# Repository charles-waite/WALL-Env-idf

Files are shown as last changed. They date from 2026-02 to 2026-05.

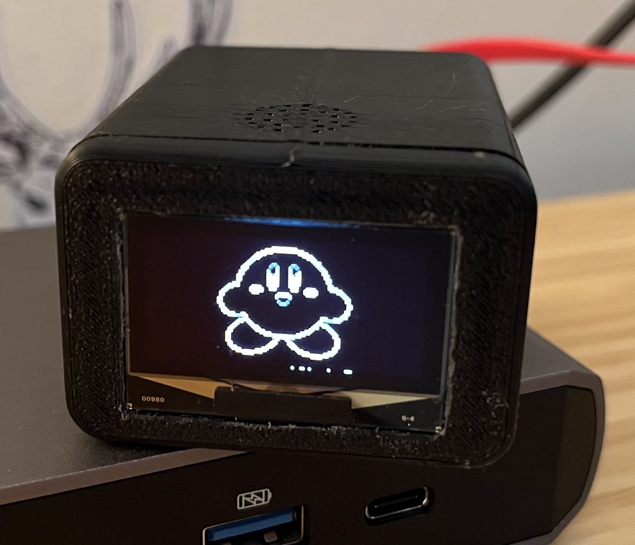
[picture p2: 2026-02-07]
reference/Kirbyartifacts.jpeg

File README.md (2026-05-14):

# WALL-Env ESP-IDF Environmental Sensor

### A compact, Matter-over-Thread environmental monitoring module built around ESP32-C6 boards and a Bosch BME680 sensor. 
It is compatible with both **Apple Home** and **Home Assistant** but requires a Thread-capable Matter controller in order to work. Apple TV 4K (2nd/3rd Gen Wi-Fi+Ethernet), HomePod (2nd Gen), and HomePod mini are all compatible.

This repository is a rewrite of the earlier [Arduino/ESP-IDF WALL-Env firmware](https://github.com/charles-waite/ESP32-Matter-Environmental-Sensor) using native ESP-IDF + esp-matter. The goal is a cleaner codebase with better Matter integration, support for Matter over Thread, board-specific build outputs, and OTA firmware update support.

## 📦 Overview

WALL-Env measures indoor environmental conditions using a Bosch BME680 with Bosch's BSEC2 library calculating accurate sensor data. The device publishes temperature, relative humidity, air quality, CO2 equivalent, and TVOC through Matter over Thread.

Optional support for a 1.3" SH1106 OLED connected via I2C shows commissioning and local status. When the device is uncommissioned, the OLED displays the Matter QR code for simple pairing to Apple Home or Home Assistant.

The firmware is Thread-only. BLE is used for Matter commissioning using an iPhone or iPad using Apple Home or the Home Assistant app. Sensor data and communication runs over Thread.

## 🧰 Hardware

| Component | Description / Notes |
|---|---|
| **Seeed Studio XIAO ESP32-C6** | Primary board target. Uses 4 MB flash and default XIAO-style I2C pins. |
| *OR* | | 
| **Generic ESP32-C6 Supermini** | Secondary board profile with separate I2C pins and Product ID. |
| **Bosch BME680** | Environmental sensor used with BSEC2 for compensated temperature, humidity, s-IAQ, eCO2, and bVOC/TVOC. Connected over I2C at `0x77`. |
| **Optional: 1.3" OLED display"** | Local display connected over I2C at `0x3C`. Current driver assumes a 128x64 panel with a 2-pixel SH1106 column offset. |
| **Standard Apple 5w USB charger** | Designed for always-on USB power. The firmware configures the node as Thread router-capable. |

###Default XIAO wiring

| XIAO ESP32-C6 Pin | Signal |
|---|---|
| GPIO22 / D4 | SDA |
| GPIO23 / D5 | SCL |
| 3V3 | 3.3 V out |
| GND | Ground |
###Default Supermini wiring

| Supermini Pin | Signal |
|---|---|
| GPIO0 | SDA |
| GPIO1 | SCL |
| 3V3 | 3.3 V out |
| GND | Ground |

##🧩 Firmware & Tooling

The firmware uses native **ESP-IDF**, Espressif **esp-matter**, OpenThread, and Bosch **BSEC2**. Arduino is not used.

**Core features**

- Matter over Thread, with BLE commissioning.
- Thread router-capable configuration for mains-powered operation.
- BME680 sensor providing accurate Temperature, Humidity, Air Quality, CO2 concentration, and TVOC measurements.
- Accuraacty compensation done via BSEC2 in low-power mode.
- Matter Time Synchronization for automated time sync.
- Partial Matter OTA support.
- BSEC2 compensation state saves to internal storage.
- Temperature calibration configurable via Serial.
- Optional 1.3" OLED UI with commissioning QR code, live sensor data, bitmap graphic support, time-based dimming and configurable display-off schedule.
- Serial diagnostics and commands over USB Serial/JTAG.

**Key project files**

| Path | Purpose |
|---|---|
| `main/app_main.cpp` | Matter node setup, endpoint creation, Thread setup, OTA requestor, serial commands. |
| `main/drivers/bsec2_app.cpp` | BSEC2 startup, BME680 I2C glue, BSEC state persistence, Matter sensor publishing, temperature profiles. |
| `main/drivers/oled_sh1106.cpp` | SH1106 OLED UI, QR rendering, time display, quiet-hours display control, Kirby/sensor rotation. |
| `main/chip_project_config.h` | Matter vendor/product identity and software/hardware version strings. |
| `wall_env.zap` | Local ZAP data model source. |
| `main/zap-generated/` | Generated Matter data model artifacts. |
| `sdkconfig.defaults` | Primary XIAO defaults and shared Matter/Thread/OLED settings. |
| `sdkconfig.boards/supermini.defaults` | Supermini board overlay. |
| `partitions.csv` | OTA-capable 4 MB ESP32-C6 partition table. |

**Managed and local components**

- `managed_components/espressif__esp_matter`
- `managed_components/espressif__button`
- `components/bsec2`
- `components/BME68x_Sensor_library`
- `components/app_reset`

## 🧱 3D Printed Enclosure

The enclosure files are kept in `enclosure/`. These STL files are intended to take a standard 5W Apple USB charger with an integrated mount for a male USB-A plug that can be wired to a small male usb-C plug to the board. Serial and firmware updates can be managed through this usb-A plug using a female to male adapter. The lids are designed to securely attach using 3x2mm neodymium magnets embedded in the case and lid itself.

**Current files**
Main enclosure body:
- `enclosure/Main Housing - Main Housing.stl`

- `enclosure/Solid Lid - Lid - Solid.stl`

> The OLED case lid and OLED retaining bracket designs are still a work in progress and are intentionally not treated as final release assets yet. Will be comleted and released very soon!

## 🔌 Build, Flash, Monitor

To aid in build and evnironment setup, there are a number of helper scripts included in the `tools/` directory. They set the ESP-IDF environment, use the correct build directories, enable ccache when available, add heartbeat logging for long builds, and avoid overlapping `idf.py` runs.

**XIAO ESP32-C6**

```sh
tools/set-target-esp32c6.sh
tools/build.sh
tools/idf.sh flash
tools/idf.sh monitor --no-reset
```

The XIAO build output is:

```text
builds/xiao_esp32c6/wall_env_idf.bin
```

**Generic ESP32-C6 Supermini**

```sh
tools/set-target-esp32c6-supermini.sh
tools/build-supermini.sh
tools/flash-supermini.sh
```

The Supermini build output is:

```text
builds/supermini_esp32c6/wall_env_idf.bin
```

**Flash an already-built image without rebuilding**

```sh
tools/idf.sh flash-bin
```

This uses the existing build artifacts and skips CMake/Ninja rebuild checks.

## 📡 Matter, Thread, and Endpoints

The device is commissioned over BLE and then operates over Thread. Wi-Fi station/AP support is disabled in project defaults.

The active runtime sensor endpoint layout is:

| Endpoint | Device / Purpose | Main clusters |
|---|---|---|
| `0` | Root Node | Basic Information, Descriptor, Access Control, Time Synchronization, OTA Requestor support. |
| `1` | Temperature Sensor | Temperature Measurement. |
| `2` | Humidity Sensor | Relative Humidity Measurement. |
| `3` | Air Quality Sensor | Air Quality, Carbon Dioxide Concentration Measurement, TVOC Concentration Measurement. |

ZAP artifacts live in `wall_env.zap` and `main/zap-generated/`. Runtime code still creates the sensor endpoints explicitly where that has produced the best controller behavior, especially in Apple Home and Home Assistant.

The firmware prints onboarding QR and manual pairing codes on every boot. If an OLED is present and the device is uncommissioned, the QR code is shown on the display.

## 🕒 Time and Display Behavior

Matter Time Synchronization is enabled and will allow the device to set an accurate time using your Matter controller. Time sync can take quite a while to activate cold boot or recommissioning, so the OLED treats unverified time values as unsynced until it confirms a successful time sync has occurred.

OLED behavior:

- Boot splash for `CONFIG_WALL_ENV_OLED_SPLASH_MS` milliseconds.
- QR-only screen while uncommissioned.
- After commissioning, 15 seconds of bitmap display followed by 15 seconds of sensor data and time and date.
- Time/date line on the sensor page.
- Unsynced time is marked visually until Matter time sync has populated the system clock.
- Quiet hours turn the display off from `CONFIG_WALL_ENV_OLED_QUIET_HOUR_START` to `CONFIG_WALL_ENV_OLED_QUIET_HOUR_END`.

Current default quiet hours:

```text
Screen Off: 10:00 PM local time
Screen On:  6:00 AM local time
```

## 🧪 Sensor Calibration and State

BSEC2 state is restored from NVS on boot and saved periodically after IAQ accuracy reaches the configured threshold. This helps IAQ and gas-derived outputs recover faster after normal reboots.

Temperature calibration is selected through persistent serial profiles:

```text
profile v1
profile v2
profile custom <offsetC>
```

**Profile v1** is deprecated and designed for the prior V1 enclosure design. 

**Profile v2** is *enabled by default* and is intended for the V2 enclosure design with better airflow and thus lower temperature compensation. 

**Profile Custom** allows you to set a custom offset. A positive integer results in a lower temperature reading. ie. `profile custom 5` will result in a raw measured temperature of 50°C to display as 45° C. The temperature offset will alter the BSEC compensation values for RH and IAQ across the board and is critical to overall accuracy.

The selected offset profile or custom value survives normal reboot, firmware flash, and Matter decommissioning. It is only cleared by erase-flash.

There is no significant difference in measured temperature with or without the OLED installed.

## ⌨️ Serial Commands

Use `tools/idf.sh monitor --no-reset` from an interactive terminal, then type commands into the serial monitor.

```text
help
decom
decommission
factoryreset
reset
profile
profile v1
profile v2
profile custom <offsetC>
thdiag
threaddiag
```

`decom` and `decommission` removes Matter fabrics and schedules a reboot so stale operational sessions and discovery state are cleared.

## 🔄 OTA Update and Release Packaging

The current partition table uses dual OTA slots on 4 MB ESP32-C6 modules and is the same for both the XIAO and generic Supermini Boards: 

```text
ota_0: 0x20000,  0x1E0000
ota_1: 0x200000, 0x1E0000
```

Before building a release or OTA image, update the firmware version with:

```sh
./tools/update-version.sh
```

The script prompts for a semantic version in `X.Y.Z` format, then updates the version fields used by ESP-IDF and Matter:

- `CMakeLists.txt` `PROJECT_VER`
- `CMakeLists.txt` `PROJECT_VER_NUMBER`
- `main/chip_project_config.h` `CHIP_DEVICE_CONFIG_DEVICE_SOFTWARE_VERSION_STRING`

`PROJECT_VER_NUMBER` is calculated automatically using:

```text
major * 10000 + minor * 100 + patch
```

For example, `1.3.3` becomes `10303`. After changing the version, rebuild each board profile so the generated firmware, OTA headers, and release artifacts all carry the same version.

Build Matter OTA images with:

```sh
./tools/build-ota.sh xiao

./tools/build-ota.sh supermini
```

The OTA script:

- Builds the selected board profile.
- Checks app size against the OTA slot with a 10% free-space margin.
- Wraps the app binary with the Matter OTA image header.
- Emits the `.ota` file and Home Assistant Matter Server local OTA `.json`.
- Uses board-specific Product IDs so XIAO and Supermini updates do not cross-apply.
- Fails if the compiled Matter software version does not match the version from `CMakeLists.txt` and `main/chip_project_config.h`.

Package a full "flash one file" image with:

```sh
./tools/package-release.sh xiao
./tools/package-release.sh supermini
```

`package-release.sh` reads the default version from `CMakeLists.txt` and writes merged full-flash images under `builds/releases/<version>/`.

Release and OTA process notes live in:

- `docs/matter_ota_requestor.md`
- `docs/matter_ota_release_policy.md`

## 🆔 Device Identity

Matter identity values are configured through `main/chip_project_config.h`, `sdkconfig.defaults`, and board overlays.

Current development IDs:

| Target | Vendor ID | Product ID |
|---|---|---|
| XIAO ESP32-C6 | `0xFFF1` | `0x8000` |
| Generic ESP32-C6 Supermini | `0xFFF1` | `0x8001` |

`0xFFF1` is a test Vendor ID. Do not use the development VID/PIDs for production distribution.

Version source of truth is updated through `tools/update-version.sh`, which keeps the CMake and Matter identity fields aligned:

```text
PROJECT_VER
PROJECT_VER_NUMBER
CHIP_DEVICE_CONFIG_DEVICE_SOFTWARE_VERSION_STRING
```

The Matter software version number uses:

```text
major * 10000 + minor * 100 + patch
```

## 🗂️ Repository Layout

| Path | Contents |
|---|---|
| `main/` | App logic, Matter integration, generated ZAP sources, OLED and sensor drivers. |
| `components/` | Local BSEC2/BME68x/app reset components. |
| `managed_components/` | ESP-IDF component manager dependencies. |
| `tools/` | Build, flash, target, OTA, release, version, and ZAP helper scripts. |
| `docs/` | OTA release policy and requestor runbook. |
| `reference/` | Datasheets, board pinouts, legacy notes, and diagnostics references. |
| `enclosure/` | Current STL enclosure assets. |
| `builds/` | Board-specific build outputs. |

---

MIT License © 2025 [CP Waite](https://github.com/charles-waite)

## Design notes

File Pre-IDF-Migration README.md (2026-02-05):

# ESP32 Matter Environmental Sensor

A compact, Matter-enabled environmental monitoring module built around the XIAO ESP32-C6 and Bosch BME680 sensor.  
This project demonstrates how to build a low-power, Wi-Fi or Thread-capable air quality sensor that integrates seamlessly into Matter-compatible ecosystems such as Apple Home, Google Home, and Home Assistant.

---

## 📦 Overview

The ESP32 Matter Environmental Sensor measures **temperature**, **humidity**, **pressure**, and **indoor air quality (IAQ)** using the Bosch BME680 environmental sensor and the BSEC2 library for accurate, compensated readings.  
An optional OLED display provides real-time readouts, while Matter support enables direct commissioning with any compatible ecosystem controller.

This project is designed for simple assembly, minimal wiring, and reliable 24/7 operation when powered from a compact USB charger.

---

## 🧰 Hardware

| Component | Description / Notes |
|---|---|
| **Seeed Studio XIAO ESP32-C6** | Main MCU; supports Wi-Fi, Thread, and BLE. Chosen for its small footprint and native Matter compatibility. |
| **Bosch BME680** | Environmental sensor measuring temperature, humidity, pressure, and gas/IAQ; connected via I²C. |
| **Apple 5W USB Charger** | Reliable, low-noise 5 V supply for continuous operation. |
| **USB-A Male Plug** | Interfaces the charger output to the device enclosure. |
| **USB-C Male Plug** | Connects to the XIAO board for power and flashing. |
| **Optional: SH1106 OLED Display (1.3")** | Displays temperature, humidity, pressure, and IAQ values locally. Connected via I²C (address `0x3C`). |

> ⚙️ *Future versions may include a VEML7700 ambient light sensor for automatic display dimming.*

---

## 🧩 Firmware & Tooling

The firmware is built with **ESP-IDF** and the **Arduino-ESP32** component, using Espressif’s **Matter** support and Bosch’s **BSEC2** library for compensated BME680 readings.

**Core Features**
- Matter over Wi-Fi or Thread
- Thread router-eligible configuration for mains-powered operation
- BME680 via BSEC2 for accurate IAQ, temperature, humidity, and pressure (s-IAQ for stationary use)
- Periodic state saving (`setState()` / `getState()`) every hour for stable IAQ tracking
- Matter Time Synchronization for local time (initial sync at commission; after reboot, sync can take up to ~10 minutes)
- OLED visualization (optional)
- Serial diagnostics (including Thread role and router eligibility)
- OLED auto-detection (prints a one-time notice if no display is found)

**Key Components**
- `managed_components/espressif__arduino-esp32` (Arduino core)
- `managed_components/espressif__esp_matter` (Matter stack)
- `components/bsec2` + `components/BME68x_Sensor_library`
- `components/oled_ssd1306_tp` (optional OLED)
- `components/qrcodeoled` (commissioning QR display)
- `components/esp32_matter_extra_endpoints` (additional Matter endpoints)

**Build & Flash**
- `idf.py set-target esp32c6`
- `idf.py build`
- `idf.py flash`
- `idf.py monitor` (watch commissioning output and Thread role)

**Hardware Flashing Guide**

App-only (device already has bootloader + partition table):
```
python -m esptool --chip esp32c6 -b 460800 --before default_reset --after hard_reset \
  write_flash 0x30000 build/WALL-Env_Sensor.bin
```

Full flash (first-time flash or after partition changes):
```
python -m esptool --chip esp32c6 -b 460800 --before default_reset --after hard_reset \
  write_flash 0x0 build/bootloader/bootloader.bin \
             0x8000 build/partition_table/partition-table.bin \
             0x30000 build/WALL-Env_Sensor.bin
```

Single image (merge bootloader + partition table + app):
```
python -m esptool --chip esp32c6 merge_bin -o build/full_flash.bin \
  0x0 build/bootloader/bootloader.bin \
  0x8000 build/partition_table/partition-table.bin \
  0x30000 build/WALL-Env_Sensor.bin
```

**Partitioning**
- Custom partition table disables OTA (single factory app slot) to free space for data/NVS.

**Device Identity IDs**
- Device vendor/product IDs and software/hardware versions are configured via `main/chip_project_config.h`.
- Update `CHIP_DEVICE_CONFIG_DEVICE_VENDOR_NAME`, `CHIP_DEVICE_CONFIG_DEVICE_PRODUCT_NAME`,
  `CHIP_DEVICE_CONFIG_DEVICE_SOFTWARE_VERSION_STRING`, and
  `CHIP_DEVICE_CONFIG_DEFAULT_DEVICE_HARDWARE_VERSION_STRING` as needed.

---

## 🧱 3D Printed Enclosure

A simple, vented enclosure designed for passive airflow and unobtrusive wall or outlet mounting.

**Files**
- `enclosure/Main Housing - Main Housing.stl`
- `enclosure/Solid Lid - Lid - Solid.stl`
- `enclosure/1.3- Screen Lid - Hosyond - Lid - OLED.stl` *(optional display version)*
- `enclosure/1.3- Screen Lid - Hosyond - OLED Retaining Bracket.stl`

**Notes**
- The case design accommodates the XIAO ESP32-C6, BME680 breakout, and optional SH1106 OLED.
- Optimized for front-facing airflow and USB-powered mounting directly on a 5 W charger.
- Printed in PLA or PETG recommended for indoor use.

---

## 🔌 Assembly & Wiring

Connect the BME680 (and optional OLED) to the XIAO ESP32-C6 over I²C. The firmware defaults to `SDA_PIN=22` and `SCL_PIN=23` (adjust in `main/MainSensor.cpp` if your board uses different pins).

| XIAO ESP32-C6 Pin | Signal | BME680 Pin | OLED Pin (optional) | Notes |
|---|---|---|---|---|
| **GPIO22 (D4)** | SDA | SDA | SDA | I²C data line |
| **GPIO23 (D5)** | SCL | SCL | SCL | I²C clock line |
| **3V3** | 3.3 V | VIN | VCC | Power supply |
| **GND** | Ground | GND | GND | Common ground |

**Steps**
1. Wire the BME680 (and OLED) to the XIAO as shown above.  
2. Build and flash via USB-C using ESP-IDF.  
3. Power the unit using the Apple 5 W charger with USB-A → USB-C adapter.  
4. On startup, scan the QR code shown on the OLED (or via serial output) to commission the device via a Matter controller.

---

## 🧠 Future Enhancements

- Additional Thread diagnostics and routing metrics  
- OTA updates  
- Ambient light sensor integration for display dimming  
- Expanded Matter cluster support (e.g., VOC index, CO₂, etc.)

---

## 📜 License

MIT License © 2025 [CP Waite](https://github.com/charles-waite)

---

## 🖼️ Preview

*(Add photos or renders here)*  
- Device mounted on charger  
- OLED displaying environmental data  
- Matter commissioning QR code  
- Enclosure render or assembly diagram

---

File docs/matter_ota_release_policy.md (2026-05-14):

# Matter OTA Release Policy

This policy defines when a WALL-Env firmware build is safe to publish through
Matter OTA. The OTA path is for routine firmware updates only. Changes that
alter the boot, flash, identity, or persistent-storage contract require a manual
flash and validation pass before OTA is used again.

## OTA Eligibility Preconditions

A device is OTA-eligible only if all of the following are true:

- The device was previously flashed with the OTA-capable partition layout
  (`otadata`, `ota_0`, `ota_1`) and successfully booted at least once.
- The running firmware has OTA Requestor enabled and endpoint 0 exposes the OTA
  Requestor cluster.
- Bootloader rollback support remains enabled and operational.
- The candidate image matches the device VID/PID and has a strictly higher
  `SoftwareVersion`.

If any condition above is false, OTA must be disallowed and the device must be
updated by manual erase/flash first.

## Supported OTA Targets

Local development uses VID `0xFFF1`.

- XIAO ESP32-C6: PID `0x8000`
- Supermini ESP32-C6: PID `0x8001`

Each board target must publish its own OTA image and metadata JSON. Do not reuse
an OTA image across PIDs, even if the ESP32-C6 chip is the same.

## Versioning Rules

`SoftwareVersion` is the authoritative update ordering field. It must increase
monotonically for every OTA-published image for a given PID.

Use this conversion:

```text
major * 10000 + minor * 100 + patch
```

Examples:

```text
1.2.0 -> 10200
1.3.0 -> 10300
1.3.1 -> 10301
```

Rules:

- Never publish two different images with the same VID, PID, and
  `SoftwareVersion`.
- Never publish an OTA image whose `SoftwareVersion` is lower than a version
  already deployed to that PID.
- Diagnostic or test builds must still use unique, increasing version numbers.
- `SoftwareVersionString` may be human-readable, but it does not replace the
  integer version.

Version source files:

- `tools/update-version.sh` is the supported way to change release versioning.
- `PROJECT_VER` sets the semantic software version string.
- `PROJECT_VER_NUMBER` sets the Matter numeric software version.
- `main/chip_project_config.h` must keep
  `CHIP_DEVICE_CONFIG_DEVICE_SOFTWARE_VERSION_STRING` aligned with
  `PROJECT_VER`.

`tools/update-version.sh` prompts for an `X.Y.Z` version, updates
`CMakeLists.txt`, updates `main/chip_project_config.h`, and computes the Matter
integer software version as `major * 10000 + minor * 100 + patch`. Rebuild every
target board after running it.

## OTA-Compatible Changes

These changes are normally acceptable for OTA, assuming the image still fits:

- Sensor/display/application logic changes.
- Matter attribute behavior changes that preserve endpoint and cluster identity.
- Logging changes.
- Non-breaking timing, retry, threshold, and calibration changes.
- Dependency updates that do not require partition, storage, bootloader, or
  factory-data changes.

## Manual-Flash-Only Changes

Do not deploy these by OTA to already-fielded devices:

- `partitions.csv` changes, including partition offsets, sizes, names, flags, or
  adding/removing partitions.
- Any change to OTA slot geometry (`ota_0`/`ota_1` offsets or sizes) or OTA data
  partition behavior.
- Bootloader configuration changes that alter rollback, secure boot, flash
  encryption, app signing, or image validation behavior.
- Changes to `CONFIG_PARTITION_TABLE_*`.
- Changes to `CONFIG_BOOTLOADER_APP_ROLLBACK_ENABLE` or rollback confirmation
  semantics.
- Changes to `CONFIG_SECURE_BOOT`, `CONFIG_FLASH_ENCRYPTION_ENABLED`, signing
  keys, encryption keys, or secure-cert storage format.
- Changes to NVS partition name, NVS schema, factory-data partition, DAC/provider
  config, or Matter persistent-storage compatibility that are not explicitly
  migrated in-app.
- Changes to VID, PID, discriminator/passcode generation model, commissioning
  flow, or production identity metadata.
- Endpoint/device-type/cluster model changes that could make the existing HA
  Matter node representation invalid without re-interview or recommissioning.
- Switching Thread/Wi-Fi transport mode or disabling Matter-over-Thread support.
- Any change where a failed boot cannot be expected to roll back safely.

If one of these changes is required, manually flash one device, validate
commissioning, persistence, rollback, and HA interview behavior, then decide
whether later routine app updates can resume over OTA.

## Provider Matching Rules

The OTA provider must reject a candidate unless all conditions are met:

- `VendorID` exactly matches requestor VID.
- `ProductID` exactly matches requestor PID.
- Candidate `SoftwareVersion` is strictly greater than requestor current version.
- If set, `MinApplicableSoftwareVersion` <= requestor current version.
- If set, `MaxApplicableSoftwareVersion` >= requestor current version.

If multiple candidates are valid, serve the highest `SoftwareVersion`.

Never serve cross-PID images or equal/lower-version images.

## Required Build Checks

`tools/build-ota.sh` is the only supported packaging path for WALL-Env OTA
images. It must:

- Build the selected board profile.
- Verify the app image fits in the `0x1E0000` OTA slot with at least 10% free.
- Wrap the app binary with a Matter OTA image header.
- Generate the `python-matter-server` local-update JSON.
- Set VID/PID according to the board target.
- Set `softwareVersion`, `softwareVersionString`, `otaFileSize`,
  `otaChecksum`, and applicability range from the generated artifacts.
- Read package version from `CMakeLists.txt` (`PROJECT_VER` and
  `PROJECT_VER_NUMBER`).
- Ask for interactive confirmation before building unless `-f` or `--force` is
  used.
- Fail if runtime firmware version fields do not match the package version.
- Default `minApplicableSoftwareVersion` to `10300` unless explicitly
  overridden.

Before copying artifacts to the Matter Server OTA directory, inspect:

```sh
python3 managed_components/espressif__esp_matter/connectedhomeip/connectedhomeip/src/app/ota_image_tool.py show \
  builds/<board>/ota/wall_env_<board>_<version>.ota
```

Confirm:

- VID and PID match the physical board.
- Version is higher than the deployed version.
- Payload size fits the OTA slot.
- Digest is present.
- `SoftwareVersion` and `SoftwareVersionString` in firmware runtime config match
  the OTA header values.

## Publishing Rules

Publish OTA files as pairs:

```text
wall_env_<board>_<version>.ota
wall_env_<board>_<version>.json
```

Place both files in the Matter Server OTA provider directory. For the current
HAOS Matter Server setup, the host-visible path is:

```text
/addon_configs/core_matter_server/ota
```

The Matter Server add-on sees that directory as:

```text
/config/ota
```

The add-on must be started with:

```text
--ota-provider-dir /config/ota
```

Restart the Matter Server add-on after adding or removing local update JSON
files, because local updates are loaded at startup.

## Deployment Checklist

For each OTA release:

1. Confirm the intended target board and PID.
2. Confirm the currently deployed `SoftwareVersion`.
3. Confirm the device is already on OTA-capable partition layout and requestor
   firmware.
4. Choose the next monotonic version.
5. Run `tools/update-version.sh`.
6. Build with `tools/build-ota.sh <xiao|supermini>`.
7. Inspect the OTA header and generated JSON.
8. Verify provider-side matching will exclude wrong PID and lower/equal
   versions.
9. Copy both generated files to the Matter Server OTA directory.
10. Restart the Matter Server add-on.
11. Use the Matter Server UI or HA update entity to verify the update source is
    `local`.
12. Update one test node first.
13. Confirm download, reboot, rollback validation, and new version reporting.
14. Leave the OTA files in place only while that version should remain
    available.

## Post-Update Validation

After update, verify:

- Device returns online on the same Matter fabric.
- `BasicInformation.SoftwareVersion` matches the target integer.
- `BasicInformation.SoftwareVersionString` matches the target string.
- `OtaSoftwareUpdateRequestor.UpdateState` returns to idle.
- ESP-IDF rollback validation marks the new app valid.
- Sensor startup, display startup, BSEC startup, and Matter startup all succeed.
- HA subscriptions resume without needing recommissioning.

If the device rolls back, remove the JSON from the OTA provider directory and
restart Matter Server before investigating.

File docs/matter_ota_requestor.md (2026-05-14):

# Matter OTA Requestor Runbook

This project uses Matter OTA Requestor over Thread/BDX with ESP-IDF dual OTA app partitions on 4 MB flash.

## Partition And Fallback Model

The shared XIAO and Supermini partition table has `otadata`, `ota_0`, and `ota_1`; each app slot is `0x1E0000` bytes. After this partition-table change, do a full flash or erase/reflash once. App-only flashing over the old table is not sufficient.

ESP-IDF rollback is enabled with `CONFIG_BOOTLOADER_APP_ROLLBACK_ENABLE=y`. A newly downloaded OTA image boots as pending verify. The app marks it valid only after Matter startup and sensor startup succeed. If the app crashes, resets, or fails validation before marking itself valid, the bootloader rolls back to the previous valid app partition.

## Identity And Versioning

Local bring-up keeps test VID `0xFFF1`.

- XIAO PID: `0x8000`
- Supermini PID: `0x8001`

Do not publish production OTA images with the test VID/PIDs. Replace them with assigned production values across `sdkconfig.defaults`, board defaults, `main/chip_project_config.h`-derived metadata, onboarding data, and OTA image headers.

Software version numbers are monotonic SemVer integers:

```text
major * 10000 + minor * 100 + patch
```

For example, `1.3.0` becomes `10300`. OTA providers and requestors compare the integer, not only the display string.

Version source of truth is `CMakeLists.txt`:

- `PROJECT_VER`: semantic version string.
- `PROJECT_VER_NUMBER`: Matter integer software version.

Use `tools/update-version.sh` to change release versions. It prompts for an
`X.Y.Z` semantic version, computes `PROJECT_VER_NUMBER` as
`major * 10000 + minor * 100 + patch`, and updates:

- `CMakeLists.txt` `PROJECT_VER`
- `CMakeLists.txt` `PROJECT_VER_NUMBER`
- `main/chip_project_config.h` `CHIP_DEVICE_CONFIG_DEVICE_SOFTWARE_VERSION_STRING`

Do not edit only one of these fields by hand. `tools/build-ota.sh` verifies that
the compiled Matter software version, CMake version, and OTA header version all
match before it writes an OTA image.

## Build And Package

The Matter OTA image tool is vendored with esp-matter:

```sh
managed_components/espressif__esp_matter/connectedhomeip/connectedhomeip/src/app/ota_image_tool.py
```

The tool imports CHIP Python TLV helpers from the same managed component. If Python import errors occur, initialize the ESP-IDF environment first:

```sh
source "$HOME/esp-idf/export.sh"
```

Build and package OTA images:

```sh
tools/update-version.sh
tools/build-ota.sh xiao
tools/build-ota.sh supermini
```

The script reads the version from `CMakeLists.txt`, asks for confirmation,
builds the selected board, checks that `wall_env_idf.bin` leaves at least 10%
free in the `0x1E0000` OTA slot, creates the Matter OTA image header with
SHA-256 digest, emits the local Matter Server JSON, and prints
`ota_image_tool.py show` output. Use `-f` or `--force` to skip confirmation in
automation. If `--min-version` is omitted, it defaults to `10300` so pre-OTA
baseline firmware is excluded by applicability bounds.

Raw tool form:

```sh
python3 managed_components/espressif__esp_matter/connectedhomeip/connectedhomeip/src/app/ota_image_tool.py create \
  -v 0xFFF1 -p 0x8000 -vn 10300 -vs 1.3.0 -da sha256 \
  builds/xiao_esp32c6/wall_env_idf.bin \
  builds/xiao_esp32c6/ota/wall_env_xiao_1.3.0.ota
```

Use PID `0x8001` and the Supermini build path for Supermini images.

## Provider Setup

The validated local setup uses Home Assistant OS Matter Server's built-in local
OTA flow. `python-matter-server` loads local update metadata from its
`--ota-provider-dir`, starts `chip-ota-provider-app`, commissions a temporary OTA
Provider node into the HA fabric, announces the provider to the target node, and
then stops the provider after the update.

For the current HAOS Matter Server add-on setup:

```text
Host-visible path: /addon_configs/core_matter_server/ota
Add-on path:       /config/ota
Add-on argument:   --ota-provider-dir /config/ota
```

Copy the generated `.ota` and `.json` pair from `tools/build-ota.sh` into that
directory, restart the Matter Server add-on, then use the Matter Server UI or HA
update entity to check and install the local update.

Manual `chip-tool` provider setup remains useful for isolated protocol testing,
but it is not the primary WALL-Env deployment path.

See `docs/matter_ota_release_policy.md` before publishing OTA images.

## Manual Provider Reference

Use this only for standalone CHIP testing outside the HA Matter Server local OTA
flow.

Typical provider shape:

```sh
chip-ota-provider-app \
  --filepath builds/xiao_esp32c6/ota/wall_env_xiao_1.3.0.ota \
  --discriminator 3841 \
  --passcode 20202021
```

Exact binary name and options vary by CHIP build. Use local `--help` output as canonical.

Commission the OTA Provider onto the same fabric as the sensor, then either write `DefaultOTAProviders` on the sensor or announce the provider. Fill in the operational Node IDs and fabric index from your controller:

```sh
chip-tool otasoftwareupdaterequestor write default-ota-providers \
  '[{"providerNodeID": <PROVIDER_NODE_ID>, "endpoint": 0, "fabricIndex": <FABRIC_INDEX>}]' \
  <SENSOR_NODE_ID> 0
```

Or announce the provider:

```sh
chip-tool otasoftwareupdaterequestor announce-ota-provider \
  <PROVIDER_NODE_ID> 0 0 0xFFF1 <SENSOR_NODE_ID> 0
```

If your `chip-tool` syntax differs, run:

```sh
chip-tool otasoftwareupdaterequestor --help
```

## Validation Checklist

- Full-flash once after the partition change.
- Confirm boot logs show `otadata`, `ota_0`, `ota_1`, active partition, next OTA partition, VID/PID, and software version.
- Confirm endpoint 0 exposes Root Node plus OTA Requestor device type, OTA Software Update Requestor server cluster, OTA Software Update Provider client cluster, and Binding.
- Confirm the OTA image header PID matches the target board.
- Test wrong-PID, lower/equal-version, and truncated images; the requestor should reject or fail safely.
- During a real OTA, confirm reboot into the opposite app slot, rollback validation, and preserved Matter fabric/NVS state.

Matter OTA image headers provide payload integrity through the digest. Firmware authenticity/signing is separate production hardening unless secure boot and signed images are enabled.

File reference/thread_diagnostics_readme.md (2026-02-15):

# Thread Diagnostics (`0x0035`) Quick Test With `chip-tool`

This is a ground-truth check for Matter Thread diagnostics before relying on Home Assistant UI exposure.

## 1) Prerequisites

- Device is commissioned and on Thread.
- Your Mac/Linux host is on the same LAN as the Thread Border Router.
- `chip-tool` is installed and runnable.
- You know:
  - `NODE_ID` (your device node id on that fabric)
  - `EP` (endpoint hosting Thread Network Diagnostics; root endpoint is usually `0`)

## 2) Confirm command syntax on your `chip-tool` build

```bash
chip-tool any read-by-id --help
chip-tool any subscribe-by-id --help
```

Different chip-tool versions vary slightly in argument order/flags. Use the local help as canonical.

## 3) One-shot reads (selected attributes)

Use cluster `0x0035` (Thread Network Diagnostics):

```bash
# routingRole (0x0001)
chip-tool any read-by-id 0x0035 0x0001 ${EP} ${NODE_ID}

# neighborTable (0x0007) - includes averageRssi/lastRssi/lqi/isChild
chip-tool any read-by-id 0x0035 0x0007 ${EP} ${NODE_ID}

# routeTable (0x0008) - includes routerId/nextHop/pathCost/linkEstablished
chip-tool any read-by-id 0x0035 0x0008 ${EP} ${NODE_ID}

# parentChangeCount (0x0015)
chip-tool any read-by-id 0x0035 0x0015 ${EP} ${NODE_ID}

# txRetryCount (0x0021)
chip-tool any read-by-id 0x0035 0x0021 ${EP} ${NODE_ID}

# txErrCcaCount (0x0024)
chip-tool any read-by-id 0x0035 0x0024 ${EP} ${NODE_ID}

# rxErrNoFrameCount (0x0032)
chip-tool any read-by-id 0x0035 0x0032 ${EP} ${NODE_ID}

# rxErrUnknownNeighborCount (0x0033)
chip-tool any read-by-id 0x0035 0x0033 ${EP} ${NODE_ID}

# rxErrInvalidSrcAddrCount (0x0034)
chip-tool any read-by-id 0x0035 0x0034 ${EP} ${NODE_ID}

# rxErrSecCount (0x0035)
chip-tool any read-by-id 0x0035 0x0035 ${EP} ${NODE_ID}

# rxErrFcsCount (0x0036)
chip-tool any read-by-id 0x0035 0x0036 ${EP} ${NODE_ID}

# rxErrOtherCount (0x0037)
chip-tool any read-by-id 0x0035 0x0037 ${EP} ${NODE_ID}
```

## 4) Subscribe to trend over time

Use min/max report intervals that fit your test (example: 2s min, 60s max).

```bash
# parentChangeCount trend
chip-tool any subscribe-by-id 0x0035 0x0015 2 60 ${EP} ${NODE_ID}

# txRetryCount trend
chip-tool any subscribe-by-id 0x0035 0x0021 2 60 ${EP} ${NODE_ID}

# txErrCcaCount trend
chip-tool any subscribe-by-id 0x0035 0x0024 2 60 ${EP} ${NODE_ID}
```

Run one subscription per terminal tab for easier reading.

## 5) Interpreting quickly

- `routingRole`: `child`, `router`, `leader` transitions are expected in some topologies.
- `neighborTable`: more negative RSSI means weaker signal (e.g. `-85 dBm` weaker than `-65 dBm`).
- `parentChangeCount`: rising quickly implies unstable parent link/roaming.
- `txRetryCount` and `txErrCcaCount`: increasing rapidly suggests RF contention/weak links.
- `rxErr*` counters: persistent growth can indicate interference, collisions, or malformed/noisy traffic.

## 6) If HA does not show these values

- If `chip-tool` reads/subscriptions succeed: firmware + Matter cluster are working; HA UI/entity mapping is the gap.
- If `chip-tool` fails too: troubleshoot endpoint/cluster availability and commissioning/fabric/reachability first.

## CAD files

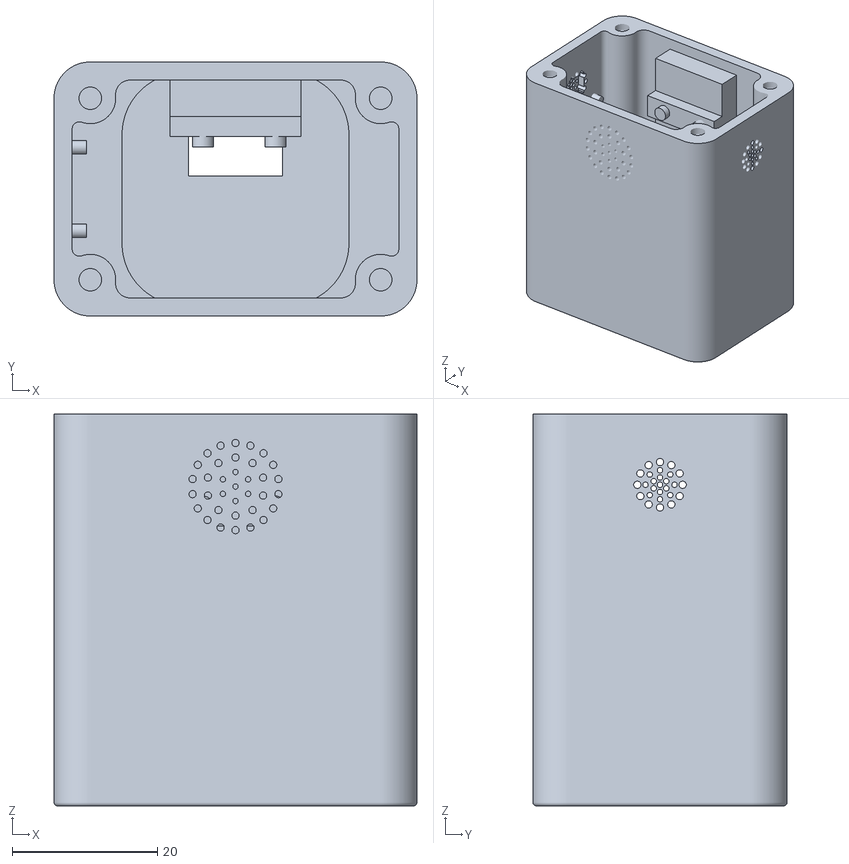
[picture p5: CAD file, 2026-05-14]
enclosure/Main Housing - Main Housing.stl
50.0 x 35.0 x 54.0

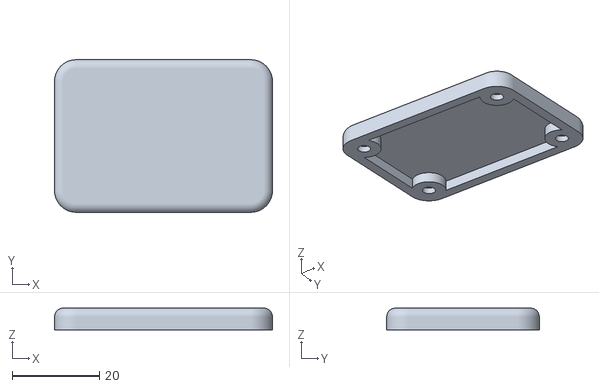
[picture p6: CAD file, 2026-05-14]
enclosure/Solid Lid - Lid - Solid.stl
50.0 x 35.0 x 5.00

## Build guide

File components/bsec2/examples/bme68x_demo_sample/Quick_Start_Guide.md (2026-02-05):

# BME688 Development Kit-Firmware-Quick-Start-Guide

## Pre-requisites

Follow the Installation and getting started in the [README.md](../../README.md).

## Instructions to build the **bme68x_demo_sample**

1. Install the following Arduino libraries under Sketch->Include Library->Manage Libraries

	- ArduinoJson (tested for 6.19.4 by Benoit Blanchon)

	- RTClib (tested for 2.0.3 by Adafruit)

    	- Click OK, when asked to install needed dependencies

	- SdFat (tested for 2.1.2 by Bill Greiman)

2. Open the 'bme68x_demo_sample.ino' file from the path - Bosch_BSEC2_Library/examples/bme68x_demo_sample

3. Connect your board via USB

	- Select "Adafruit ESP32 Feather" in the Arduino IDE under Tools->Board

	- Select your COM Port under Tools->Port

5. Upload the firmware

	- If you have a coin cell (CR1220) for the RTC, make sure it is inserted before flashing the board

	- When the board is flashed, don't unmount the coin cell, if not necessary

5. Wait for the board to be flashed and then disconnect it

	- Last line in the Arduino command line should be: "Hard resetting via RTS pin..."

6. To start the data logging, insert an SD-card with a '.bmeconfig file' in it (generated using BME AI studio) and connect power supply
  
7. A red LED blinking with 1Hz indicates a successful data logging, a faster blinking indicates an error during the initialization (RTC, SD or Bluetooth)

## Additional Note

The 'Bosch_BSEC2_Library' has a 'src' folder with the following files essential for running application-

- header files - bsec_datatypes.h, bsec_interface.h and bsec_interface_multi.h(under folder 'inc')

- esp32 library - static library (under 'esp32')

## More about Demo Application Code (Bme68x_demo_sample.ino Sketch):

This is an example code for datalogging and integration of BSEC2x library in BME688 development kit,
which has been designed to work with Adafruit ESP32 Feather Board.

The example code will primarily operate in two modes-

**a. DEMO_RECORDING_MODE**

**b. DEMO_TEST_ALGORITHM_MODE**

- Multi sensor support is available in DEMO_RECORDING_MODE upto 8 sensors.
- Modify NUM_BME68X_UNITS between 0 to 8, where 0 to 7 is for sensor numbers 1 to 8 respectively and 8 is for running all 8 sensors parallely.
- Multi sensor support is available in DEMO_TEST_ALGORITHM_MODE upto 4 sensors.
- Modify NUM_BME68X_UNITS between 0 to 4, where 0 to 3 is for sensor numbers 1 to 4 respectively and 4 is for running all 4 sensors parallely.

### Note:

- After successfully flashing the firmware, "DEMO_RECORDING_MODE" is the default mode set in the example.

- An initial check for the availability of sensor board configuration file (.bmeconfig) inside SD card is performed.

- For DEMO_RECORDING_MODE, once .bmeconfig file has been detected, it will initialize and set the heater profiles for all the bme688 sensors with the provided configuration and create bme68x datalogger output file (with '.bmerawdata' extension).

- Until the user connects the board to the BME688 demo application through Bluetooth LE and switches to "DEMO_TEST_ALGORITHM_MODE", it will continue to collect the data in DEMO_RECORDING_MODE.

- When it comes to 'DEMO_TEST_ALGORITHM_MODE' (connecting over bluetooth and set to "DEMO_TEST_ALGORITHM_MODE"), initialization of sensor and BSEC library is undertaken.

- Furthermore, configuring with the BSEC config file (generated out of training through BME AI Studio or a default configuration from the BSEC website release package) and subscribing for the desired virtual outputs with the supported sample rate is complete, an output data file is created with the '.aiprediction' extension.

- If the Bluetooth is disconnected, the board continuous to work in the existing mode unless power is reset.

- The default bootup mode is "DEMO_RECORDING_MODE".

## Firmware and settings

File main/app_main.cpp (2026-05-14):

/*
   This example code is in the Public Domain (or CC0 licensed, at your option.)

   Unless required by applicable law or agreed to in writing, this
   software is distributed on an "AS IS" BASIS, WITHOUT WARRANTIES OR
   CONDITIONS OF ANY KIND, either express or implied.
*/

#include <app/server/CommissioningWindowManager.h>
#include <app/server/Dnssd.h>
#include <app/server/Server.h>
#include <app/clusters/ota-requestor/BDXDownloader.h>
#include <app/clusters/ota-requestor/DefaultOTARequestor.h>
#include <app/clusters/ota-requestor/DefaultOTARequestorDriver.h>
#include <app/clusters/ota-requestor/DefaultOTARequestorStorage.h>
#include <app/clusters/ota-requestor/OTARequestorInterface.h>
#include <app-common/zap-generated/ids/Attributes.h>
#include <app-common/zap-generated/ids/Clusters.h>
#include <lib/core/CHIPError.h>
#include <platform/ESP32/OTAImageProcessorImpl.h>
#include <platform/ConnectivityManager.h>
#include <platform/ThreadStackManager.h>
#include <button_gpio.h>
#include <iot_button.h>
#include <esp_err.h>
#include <esp_log.h>
#include <esp_ota_ops.h>
#include <esp_system.h>
#include <driver/usb_serial_jtag.h>
#include <freertos/FreeRTOS.h>
#include <freertos/task.h>
#include <nvs_flash.h>

#include <app_openthread_config.h>
#include <app_reset.h>
#include <esp_matter.h>
#include <esp_matter_attribute.h>
#include <esp_matter_cluster.h>
#include <esp_matter_endpoint.h>
#include <setup_payload/OnboardingCodesUtil.h>
#include <cctype>
#include <cstdlib>
#include <cstring>
#include <inttypes.h>

#if CHIP_DEVICE_CONFIG_ENABLE_THREAD
#include <openthread/link.h>
#include <openthread/platform/radio.h>
#include <openthread/thread.h>
#if CHIP_DEVICE_CONFIG_THREAD_FTD
#include <openthread/thread_ftd.h>
#endif // CHIP_DEVICE_CONFIG_THREAD_FTD
#endif // CHIP_DEVICE_CONFIG_ENABLE_THREAD

// drivers implemented by this example
#include <drivers/bsec2_app.h>
#include <drivers/oled_sh1106.h>

static const char *TAG = "app_main";
static constexpr uint32_t kTimeSyncClusterId = chip::app::Clusters::TimeSynchronization::Id;
static constexpr int kResetButtonGpio = CONFIG_WALL_ENV_RESET_BUTTON_GPIO;
static bool s_reboot_after_decom = false;
static bool s_decom_in_progress = false;

#if CONFIG_ENABLE_OTA_REQUESTOR
static chip::DefaultOTARequestor s_ota_requestor;
static chip::DeviceLayer::DefaultOTARequestorDriver s_ota_driver;
static chip::DefaultOTARequestorStorage s_ota_storage;
static chip::BDXDownloader s_ota_downloader;
static chip::OTAImageProcessorImpl s_ota_image_processor;
#endif

#define ABORT_APP_ON_FAILURE(condition, log_action) \
  do { \
    if (!(condition)) { \
      log_action; \
      abort(); \
    } \
  } while (0)

enum class decom_state_t : uint8_t {
    kIdle = 0,
    kAccepted,
    kDeleteRequested,
    kFabricEvent,
    kServicesReset,
    kRebootScheduled,
};

static decom_state_t s_decom_state = decom_state_t::kIdle;

static const char *decom_state_str(decom_state_t state)
{
    switch (state) {
    case decom_state_t::kIdle:
        return "idle";
    case decom_state_t::kAccepted:
        return "accepted";
    case decom_state_t::kDeleteRequested:
        return "delete_requested";
    case decom_state_t::kFabricEvent:
        return "fabric_event";
    case decom_state_t::kServicesReset:
        return "services_reset";
    case decom_state_t::kRebootScheduled:
        return "reboot_scheduled";
    default:
        return "unknown";
    }
}

static void set_decom_state(decom_state_t next, const char *reason)
{
    s_decom_state = next;
    ESP_LOGI(TAG, "decom: state=%s (%s)", decom_state_str(next), reason ? reason : "n/a");
}

static const char *attribute_cb_type_str(esp_matter::attribute::callback_type_t type)
{
    switch (type) {
    case esp_matter::attribute::PRE_UPDATE:
        return "PRE_UPDATE";
    case esp_matter::attribute::POST_UPDATE:
        return "POST_UPDATE";
    case esp_matter::attribute::READ:
        return "READ";
    case esp_matter::attribute::WRITE:
        return "WRITE";
    default:
        return "UNKNOWN";
    }
}

#if CHIP_DEVICE_CONFIG_ENABLE_THREAD
static const char *thread_role_str(otDeviceRole role)
{
    switch (role) {
    case OT_DEVICE_ROLE_DISABLED:
        return "disabled";
    case OT_DEVICE_ROLE_DETACHED:
        return "detached";
    case OT_DEVICE_ROLE_CHILD:
        return "child";
    case OT_DEVICE_ROLE_ROUTER:
        return "router";
    case OT_DEVICE_ROLE_LEADER:
        return "leader";
    default:
        return "unknown";
    }
}

static void log_thread_diagnostics_snapshot()
{
    chip::DeviceLayer::ThreadStackMgr().LockThreadStack();
    otInstance *ot_inst = chip::DeviceLayer::ThreadStackMgrImpl().OTInstance();
    if (!ot_inst) {
        chip::DeviceLayer::ThreadStackMgr().UnlockThreadStack();
        ESP_LOGW(TAG, "thdiag: OpenThread instance unavailable");
        return;
    }

    const otDeviceRole role = otThreadGetDeviceRole(ot_inst);
    ESP_LOGI(TAG, "thdiag: role=%s channel=%u panid=0x%04X rloc16=0x%04X leaderRouterId=%u",
             thread_role_str(role), otLinkGetChannel(ot_inst), otLinkGetPanId(ot_inst),
             otThreadGetRloc16(ot_inst), otThreadGetLeaderRouterId(ot_inst));

    otRouterInfo parent_info;
    const otError parent_err = otThreadGetParentInfo(ot_inst, &parent_info);
    if (parent_err == OT_ERROR_NONE) {
        const int parent_router_id = (parent_info.mRloc16 >> 10) & 0x3F;
        int8_t parent_avg_rssi = OT_RADIO_RSSI_INVALID;
        int8_t parent_last_rssi = OT_RADIO_RSSI_INVALID;
        const bool have_avg_rssi = (otThreadGetParentAverageRssi(ot_inst, &parent_avg_rssi) == OT_ERROR_NONE);
        const bool have_last_rssi = (otThreadGetParentLastRssi(ot_inst, &parent_last_rssi) == OT_ERROR_NONE);

        if (!have_avg_rssi && !have_last_rssi) {
            ESP_LOGI(TAG, "thdiag: parent rloc16=0x%04X routerId=%d avgRssi=n/a lastRssi=n/a lqiIn=%u lqiOut=%u",
                     parent_info.mRloc16, parent_router_id, parent_info.mLinkQualityIn, parent_info.mLinkQualityOut);
        } else {
            ESP_LOGI(TAG, "thdiag: parent rloc16=0x%04X routerId=%d avgRssi=%d dBm lastRssi=%d dBm lqiIn=%u lqiOut=%u",
                     parent_info.mRloc16, parent_router_id, parent_avg_rssi, parent_last_rssi,
                     parent_info.mLinkQualityIn, parent_info.mLinkQualityOut);
        }
    } else {
        ESP_LOGI(TAG, "thdiag: parent unavailable (otErr=%d)", parent_err);
    }

    const otMleCounters *mle = otThreadGetMleCounters(ot_inst);
    if (mle) {
        ESP_LOGI(TAG, "thdiag: mle detached=%u child=%u router=%u leader=%u attachAttempts=%u parentChanges=%u",
                 mle->mDetachedRole, mle->mChildRole, mle->mRouterRole, mle->mLeaderRole,
                 mle->mAttachAttempts, mle->mParentChanges);
    }

#if CHIP_DEVICE_CONFIG_THREAD_FTD
    otChildInfo child_info;
    uint16_t child_index = 0;
    uint16_t child_count = 0;
    while (otThreadGetChildInfoByIndex(ot_inst, child_index, &child_info) == OT_ERROR_NONE) {
        const int child_id = child_info.mRloc16 & 0x01FF;
        ESP_LOGI(TAG, "thdiag: child[%u] rloc16=0x%04X childId=%d timeout=%u supervsn=%u",
                 child_count, child_info.mRloc16, child_id, child_info.mTimeout, child_info.mSupervisionInterval);
        child_count++;
        child_index++;
    }
    ESP_LOGI(TAG, "thdiag: childCount=%u", child_count);
#else
    ESP_LOGI(TAG, "thdiag: child table unavailable on MTD build");
#endif

    chip::DeviceLayer::ThreadStackMgr().UnlockThreadStack();
}
#endif // CHIP_DEVICE_CONFIG_ENABLE_THREAD

extern "C" void init_network_driver();

static bool init_time_sync_cluster(esp_matter::node_t *node)
{
    if (!node) {
        return false;
    }
    esp_matter::endpoint_t *root = esp_matter::endpoint::get(node, 0);
    if (!root) {
        return false;
    }

    esp_matter::cluster::time_synchronization::config_t cfg;
    esp_matter::cluster_t *cluster =
        esp_matter::cluster::time_synchronization::create(root, &cfg, esp_matter::CLUSTER_FLAG_SERVER);
    return cluster != nullptr;
}

static const char *ota_img_state_str(esp_ota_img_states_t state)
{
    switch (state) {
    case ESP_OTA_IMG_NEW:
        return "new";
    case ESP_OTA_IMG_PENDING_VERIFY:
        return "pending_verify";
    case ESP_OTA_IMG_VALID:
        return "valid";
    case ESP_OTA_IMG_INVALID:
        return "invalid";
    case ESP_OTA_IMG_ABORTED:
        return "aborted";
    case ESP_OTA_IMG_UNDEFINED:
        return "undefined";
    default:
        return "unknown";
    }
}

static void log_ota_partition_state(const char *phase)
{
    const esp_partition_t *running = esp_ota_get_running_partition();
    const esp_partition_t *next = esp_ota_get_next_update_partition(nullptr);
    esp_ota_img_states_t state = ESP_OTA_IMG_UNDEFINED;
    esp_err_t state_err = running ? esp_ota_get_state_partition(running, &state) : ESP_ERR_NOT_FOUND;

    ESP_LOGI(TAG, "OTA %s: VID=0x%04X PID=0x%04X software=%u partition=%s offset=0x%06" PRIx32
                  " size=0x%06" PRIx32 " state=%s next=%s",
             phase, CONFIG_DEVICE_VENDOR_ID, CONFIG_DEVICE_PRODUCT_ID, CHIP_CONFIG_SOFTWARE_VERSION_NUMBER,
             running ? running->label : "none", running ? running->address : 0, running ? running->size : 0,
             state_err == ESP_OK ? ota_img_state_str(state) : "unavailable", next ? next->label : "none");
}

static bool init_ota_requestor()
{
#if CONFIG_ENABLE_OTA_REQUESTOR
    chip::DeviceLayer::PlatformMgr().LockChipStack();
    chip::Server &server = chip::Server::GetInstance();
    s_ota_storage.Init(server.GetPersistentStorage());
    chip::SetRequestorInstance(&s_ota_requestor);

    CHIP_ERROR err = s_ota_requestor.Init(server, s_ota_storage, s_ota_driver, s_ota_downloader);
    if (err != CHIP_NO_ERROR) {
        chip::DeviceLayer::PlatformMgr().UnlockChipStack();
        ESP_LOGE(TAG, "Failed to initialize OTA Requestor: %" CHIP_ERROR_FORMAT, err.Format());
        return false;
    }

    s_ota_driver.Init(&s_ota_requestor, &s_ota_image_processor);
    s_ota_image_processor.SetOTADownloader(&s_ota_downloader);
    s_ota_downloader.SetImageProcessorDelegate(&s_ota_image_processor);
    chip::DeviceLayer::PlatformMgr().UnlockChipStack();

    ESP_LOGI(TAG, "Matter OTA Requestor initialized on endpoint 0");
    return true;
#else
    ESP_LOGI(TAG, "Matter OTA Requestor disabled by sdkconfig");
    return true;
#endif
}

static bool confirm_ota_image_if_pending()
{
#if CONFIG_ENABLE_OTA_REQUESTOR
    const esp_partition_t *running = esp_ota_get_running_partition();
    if (!running) {
        ESP_LOGW(TAG, "OTA rollback validation skipped: no running partition");
        return false;
    }

    esp_ota_img_states_t state = ESP_OTA_IMG_UNDEFINED;
    esp_err_t state_err = esp_ota_get_state_partition(running, &state);
    if (state_err != ESP_OK) {
        ESP_LOGW(TAG, "OTA rollback validation skipped: state read failed err=%d", state_err);
        return false;
    }

    if (state != ESP_OTA_IMG_PENDING_VERIFY) {
        ESP_LOGI(TAG, "OTA rollback validation not required: state=%s", ota_img_state_str(state));
        return true;
    }

    CHIP_ERROR confirm_err = s_ota_image_processor.ConfirmCurrentImage();
    if (confirm_err != CHIP_NO_ERROR) {
        ESP_LOGE(TAG, "OTA image confirmation failed; leaving image pending for rollback: %" CHIP_ERROR_FORMAT,
                 confirm_err.Format());
        return false;
    }

    esp_err_t mark_err = esp_ota_mark_app_valid_cancel_rollback();
    if (mark_err != ESP_OK) {
        ESP_LOGE(TAG, "Failed to mark OTA image valid: %d", mark_err);
        return false;
    }

    ESP_LOGI(TAG, "OTA image marked valid; rollback cancelled");
    return true;
#else
    return true;
#endif
}

static void set_basic_information_defaults()
{
    // Keep SerialNumber populated for controllers that surface it in "Device info".
    static constexpr char kDefaultSerial[] = CONFIG_USE_TEST_SERIAL_NUMBER;
    if (!esp_matter::attribute::get(0, chip::app::Clusters::BasicInformation::Id,
                                    chip::app::Clusters::BasicInformation::Attributes::SerialNumber::Id)) {
        ESP_LOGW(TAG, "BasicInformation SerialNumber attribute not present; skipping default serial update");
        return;
    }
    esp_matter_attr_val_t serial_val =
        esp_matter_char_str(const_cast<char *>(kDefaultSerial), strlen(kDefaultSerial));
    esp_matter::attribute::update(0, chip::app::Clusters::BasicInformation::Id,
                                  chip::app::Clusters::BasicInformation::Attributes::SerialNumber::Id, &serial_val);
}

static void normalize_serial_command(char *cmd)
{
    if (!cmd) {
        return;
    }

    size_t len = strlen(cmd);
    if (len == 0) {
        return;
    }

    // Trim leading whitespace.
    size_t start = 0;
    while (start < len && std::isspace(static_cast<unsigned char>(cmd[start]))) {
        start++;
    }

    // Trim trailing whitespace.
    size_t end = len;
    while (end > start && std::isspace(static_cast<unsigned char>(cmd[end - 1]))) {
        end--;
    }

    size_t out = 0;
    for (size_t i = start; i < end; ++i) {
        cmd[out++] = static_cast<char>(std::tolower(static_cast<unsigned char>(cmd[i])));
    }
    cmd[out] = '\0';
}
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
extern "C" void app_main()
{
    /* Initialize the ESP NVS layer */
    esp_err_t nvs_err = nvs_flash_init();
    if (nvs_err == ESP_ERR_NVS_NO_FREE_PAGES || nvs_err == ESP_ERR_NVS_NEW_VERSION_FOUND) {
        ESP_LOGW(TAG, "NVS init returned %d; erasing NVS partition and retrying", nvs_err);
        ESP_ERROR_CHECK(nvs_flash_erase());
        nvs_err = nvs_flash_init();
    }
    ABORT_APP_ON_FAILURE(nvs_err == ESP_OK, ESP_LOGE(TAG, "Failed to initialize NVS, err:%d", nvs_err));

    // Keep monitor output readable: suppress per-attribute value dumps from esp-matter.
    esp_log_level_set("esp_matter_attribute", ESP_LOG_WARN);

    /* Initialize push button on the dev-kit to reset the device */
    esp_err_t err = factory_reset_button_register();
    ABORT_APP_ON_FAILURE(ESP_OK == err, ESP_LOGE(TAG, "Failed to initialize reset button, err:%d", err));

    // Optional OLED splash/status task (does not abort app on failure).
    (void) oled_sh1106_start();

    /* Create a Matter node (Root Node device type on endpoint 0 is added automatically) */
    esp_matter::node::config_t node_config;
    esp_matter::node_t *node = esp_matter::node::create(&node_config, app_attribute_update_cb, app_identification_cb);
    ABORT_APP_ON_FAILURE(node != nullptr, ESP_LOGE(TAG, "Failed to create Matter node"));

    // Keep temperature and humidity on dedicated endpoints for better Apple Home UI mapping.
    esp_matter::endpoint::temperature_sensor::config_t temp_sensor_cfg;
    esp_matter::endpoint_t *temp_ep = esp_matter::endpoint::temperature_sensor::create(node, &temp_sensor_cfg, 0, nullptr);
    ABORT_APP_ON_FAILURE(temp_ep != nullptr, ESP_LOGE(TAG, "Failed to create temperature endpoint"));

    esp_matter::endpoint::humidity_sensor::config_t humidity_sensor_cfg;
    esp_matter::endpoint_t *humidity_ep = esp_matter::endpoint::humidity_sensor::create(node, &humidity_sensor_cfg, 0, nullptr);
    ABORT_APP_ON_FAILURE(humidity_ep != nullptr, ESP_LOGE(TAG, "Failed to create humidity endpoint"));

    // Keep AQ as a dedicated Air Quality Sensor endpoint.
    esp_matter::endpoint_t *aq_ep = esp_matter::endpoint::create(node, 0, nullptr);
    ABORT_APP_ON_FAILURE(aq_ep != nullptr, ESP_LOGE(TAG, "Failed to create air-quality endpoint"));
    esp_matter::cluster::descriptor::config_t descriptor_cfg;
    ABORT_APP_ON_FAILURE(esp_matter::cluster::descriptor::create(aq_ep, &descriptor_cfg, esp_matter::CLUSTER_FLAG_SERVER) != nullptr,
                         ESP_LOGE(TAG, "Failed to create descriptor cluster on AQ endpoint"));
    ABORT_APP_ON_FAILURE(
        esp_matter::endpoint::add_device_type(aq_ep, ESP_MATTER_AIR_QUALITY_SENSOR_DEVICE_TYPE_ID,
                                              ESP_MATTER_AIR_QUALITY_SENSOR_DEVICE_TYPE_VERSION) == ESP_OK,
        ESP_LOGE(TAG, "Failed to add air-quality device type"));
    esp_matter::cluster::identify::config_t identify_cfg;
    ABORT_APP_ON_FAILURE(esp_matter::cluster::identify::create(aq_ep, &identify_cfg, esp_matter::CLUSTER_FLAG_SERVER) != nullptr,
                         ESP_LOGE(TAG, "Failed to create identify cluster on AQ endpoint"));

    esp_matter::cluster_t *aq_cluster = esp_matter::cluster::create(aq_ep, chip::app::Clusters::AirQuality::Id, esp_matter::CLUSTER_FLAG_SERVER);
    ABORT_APP_ON_FAILURE(aq_cluster != nullptr, ESP_LOGE(TAG, "Failed to create AirQuality cluster"));
    ABORT_APP_ON_FAILURE(esp_matter::cluster::global::attribute::create_feature_map(aq_cluster, 0) != nullptr,
                         ESP_LOGE(TAG, "Failed to create AirQuality FeatureMap"));
    ABORT_APP_ON_FAILURE(
        esp_matter::attribute::create(
            aq_cluster, chip::app::Clusters::AirQuality::Attributes::AirQuality::Id, esp_matter::ATTRIBUTE_FLAG_NONE,
            esp_matter_enum8(chip::to_underlying(chip::app::Clusters::AirQuality::AirQualityEnum::kUnknown))) != nullptr,
        ESP_LOGE(TAG, "Failed to create AirQuality measured-value attribute"));
    ABORT_APP_ON_FAILURE(esp_matter::cluster::global::attribute::create_cluster_revision(aq_cluster, 1) != nullptr,
                         ESP_LOGE(TAG, "Failed to create AirQuality ClusterRevision"));

    // Add CO2 concentration cluster on the air-quality endpoint.
    esp_matter::cluster::carbon_dioxide_concentration_measurement::config_t co2_cfg;
    co2_cfg.feature_flags = esp_matter::cluster::carbon_dioxide_concentration_measurement::feature::numeric_measurement::get_id();
    esp_matter::cluster_t *co2_cluster =
        esp_matter::cluster::carbon_dioxide_concentration_measurement::create(aq_ep, &co2_cfg, esp_matter::CLUSTER_FLAG_SERVER);
    ABORT_APP_ON_FAILURE(co2_cluster != nullptr, ESP_LOGE(TAG, "Failed to create CO2 cluster"));

    esp_matter::cluster::total_volatile_organic_compounds_concentration_measurement::config_t tvoc_cfg;
    tvoc_cfg.feature_flags = esp_matter::cluster::concentration_measurement::feature::numeric_measurement::get_id();
    tvoc_cfg.features.numeric_measurement.measurement_unit = 0x00; // ppm
    esp_matter::cluster_t *tvoc_cluster =
        esp_matter::cluster::total_volatile_organic_compounds_concentration_measurement::create(
            aq_ep, &tvoc_cfg, esp_matter::CLUSTER_FLAG_SERVER);
    ABORT_APP_ON_FAILURE(tvoc_cluster != nullptr, ESP_LOGE(TAG, "Failed to create TVOC cluster"));

    const uint16_t temp_endpoint_id = esp_matter::endpoint::get_id(temp_ep);
    const uint16_t humidity_endpoint_id = esp_matter::endpoint::get_id(humidity_ep);
    const uint16_t air_quality_endpoint_id = esp_matter::endpoint::get_id(aq_ep);
    ESP_LOGI(TAG, "Sensor endpoints: temp=%u humidity=%u aq/co2/tvoc=%u",
             temp_endpoint_id, humidity_endpoint_id, air_quality_endpoint_id);

    // Keep Time Sync available on endpoint 0. If ZAP already instantiated this cluster,
    // create() is a no-op and returns the existing instance.
    ABORT_APP_ON_FAILURE(init_time_sync_cluster(node), ESP_LOGE(TAG, "Failed to ensure Time Synchronization cluster on endpoint 0"));

#if CHIP_DEVICE_CONFIG_ENABLE_THREAD
    /* Set OpenThread platform config */
    esp_openthread_platform_config_t config = {
        .radio_config = ESP_OPENTHREAD_DEFAULT_RADIO_CONFIG(),
        .host_config = ESP_OPENTHREAD_DEFAULT_HOST_CONFIG(),
        .port_config = ESP_OPENTHREAD_DEFAULT_PORT_CONFIG(),
    };
    set_openthread_platform_config(&config);
#endif

    // Initialize network glue early so that when CHIP brings up mDNS/DNS-SD during
    // esp_matter::start(), it's already able to bind to the OpenThread netif.
    init_network_driver();

    /* Matter start */
    err = esp_matter::start(app_event_cb);
    ABORT_APP_ON_FAILURE(err == ESP_OK, ESP_LOGE(TAG, "Failed to start Matter, err:%d", err));

    ABORT_APP_ON_FAILURE(init_ota_requestor(), ESP_LOGE(TAG, "Failed to initialize OTA Requestor"));
    log_ota_partition_state("boot");

    set_basic_information_defaults();
    log_boot_commissioning_state();

#if CHIP_DEVICE_CONFIG_ENABLE_THREAD
    // Force Router-capable behavior for better Thread mesh relay coverage.
    if (chip::DeviceLayer::ConnectivityMgr().SetThreadDeviceType(
            chip::DeviceLayer::ConnectivityManager::kThreadDeviceType_Router) != CHIP_NO_ERROR) {
        ESP_LOGW(TAG, "Failed to set Thread device type to Router");
    } else {
        ESP_LOGI(TAG, "Thread device type set to Router");
    }
#endif

    if (xTaskCreate(serial_command_task, "serial_cmd", 4096, nullptr, 4, nullptr) != pdPASS) {
        ESP_LOGW(TAG, "Failed to start serial command task");
    }

    // Print commissioning codes on every boot to simplify bring-up/testing.
    ESP_LOGI(TAG, "Matter commissioning codes:");
    PrintOnboardingCodes(chip::RendezvousInformationFlags(chip::RendezvousInformationFlag::kBLE));
    push_commissioning_codes_to_oled();
    update_oled_commissioning_state();

    // Start BSEC2 processing loop (updates split sensor endpoints).
    bsec2_app_config_t bsec_cfg = {
        .temp_endpoint = temp_endpoint_id,
        .humidity_endpoint = humidity_endpoint_id,
        .air_quality_endpoint = air_quality_endpoint_id,
        .co2_endpoint = air_quality_endpoint_id,
        .tvoc_endpoint = air_quality_endpoint_id,
    };
    err = bsec2_app_start(&bsec_cfg);
    if (err != ESP_OK) {
        ESP_LOGW(TAG, "BSEC2 init failed (%d); continuing without sensor publishing", err);
    }

    (void) confirm_ota_image_if_pending();
    log_ota_partition_state("validated");
}

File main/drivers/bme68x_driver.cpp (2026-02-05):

/*
   This example code is in the Public Domain (or CC0 licensed, at your option.)

   Unless required by applicable law or agreed to in writing, this
   software is distributed on an "AS IS" BASIS, WITHOUT WARRANTIES OR
   CONDITIONS OF ANY KIND, either express or implied.
*/

#include <esp_log.h>
#include <esp_timer.h>
#include <freertos/FreeRTOS.h>
#include <freertos/task.h>

#include <cstring>

#include <bme68x/bme68x.h>

#include "drivers/i2c_bus.h"
#include "drivers/bme68x_driver.h"

static const char *TAG = "bme68x_driver";

typedef struct {
    i2c_master_dev_handle_t dev;
    uint8_t i2c_addr;
} bme68x_i2c_ctx_t;

static bme68x_i2c_ctx_t s_i2c_ctx;
static bme68x_dev s_dev;
static bme68x_conf s_conf;
static bme68x_heatr_conf s_heatr_conf;
static bool s_initialized = false;

static void delay_us(uint32_t period_us, void *intf_ptr)
{
    (void) intf_ptr;
    const uint64_t start = esp_timer_get_time();
    const uint32_t lag_us = 5000;

    if (period_us > lag_us) {
        vTaskDelay(pdMS_TO_TICKS((period_us - lag_us) / 1000U));
        while ((esp_timer_get_time() - start) < (period_us - lag_us)) {
            vTaskDelay(pdMS_TO_TICKS(1));
        }
    }
    while ((esp_timer_get_time() - start) < period_us) {
    }
}

static int8_t i2c_write(uint8_t reg_addr, const uint8_t *reg_data, uint32_t length, void *intf_ptr)
{
    if (!intf_ptr || (!reg_data && length > 0)) {
        return BME68X_E_NULL_PTR;
    }

    const auto *ctx = static_cast<const bme68x_i2c_ctx_t *>(intf_ptr);
    if (!ctx->dev) {
        return BME68X_E_NULL_PTR;
    }

    if (length > 64) {
        return BME68X_E_INVALID_LENGTH;
    }

    uint8_t buffer[65];
    buffer[0] = reg_addr;
    if (length > 0) {
        memcpy(&buffer[1], reg_data, length);
    }

    esp_err_t err = i2c_master_transmit(ctx->dev, buffer, length + 1, 1000);
    return (err == ESP_OK) ? BME68X_OK : BME68X_E_COM_FAIL;
}

static int8_t i2c_read(uint8_t reg_addr, uint8_t *reg_data, uint32_t length, void *intf_ptr)
{
    if (!intf_ptr || (!reg_data && length > 0)) {
        return BME68X_E_NULL_PTR;
    }

    const auto *ctx = static_cast<const bme68x_i2c_ctx_t *>(intf_ptr);
    if (!ctx->dev) {
        return BME68X_E_NULL_PTR;
    }

    const uint8_t reg = reg_addr;
    esp_err_t err = i2c_master_transmit_receive(ctx->dev, &reg, 1, reg_data, length, 1000);
    return (err == ESP_OK) ? BME68X_OK : BME68X_E_COM_FAIL;
}

esp_err_t bme68x_driver_init(const bme68x_driver_config_t *config)
{
    if (!config) {
        return ESP_ERR_INVALID_ARG;
    }
    if (s_initialized) {
        return ESP_OK;
    }

    esp_err_t err = i2c_bus_add_device(config->i2c_addr, &s_i2c_ctx.dev);
    if (err != ESP_OK) {
        ESP_LOGE(TAG, "i2c_bus_add_device failed: %d", err);
        return err;
    }
    s_i2c_ctx.i2c_addr = config->i2c_addr;

    memset(&s_dev, 0, sizeof(s_dev));
    s_dev.intf = BME68X_I2C_INTF;
    s_dev.intf_ptr = &s_i2c_ctx;
    s_dev.read = i2c_read;
    s_dev.write = i2c_write;
    s_dev.delay_us = delay_us;

    int8_t rslt = bme68x_init(&s_dev);
    if (rslt != BME68X_OK) {
        ESP_LOGE(TAG, "bme68x_init failed: %d", rslt);
        return ESP_FAIL;
    }

    memset(&s_conf, 0, sizeof(s_conf));
    s_conf.os_hum = BME68X_OS_1X;
    s_conf.os_temp = BME68X_OS_2X;
    s_conf.os_pres = BME68X_OS_4X;
    s_conf.filter = BME68X_FILTER_OFF;
    s_conf.odr = BME68X_ODR_NONE;

    rslt = bme68x_set_conf(&s_conf, &s_dev);
    if (rslt != BME68X_OK) {
        ESP_LOGE(TAG, "bme68x_set_conf failed: %d", rslt);
        return ESP_FAIL;
    }

    memset(&s_heatr_conf, 0, sizeof(s_heatr_conf));
    s_heatr_conf.enable = BME68X_ENABLE;
    s_heatr_conf.heatr_temp = config->heater_temp_c;
    s_heatr_conf.heatr_dur = config->heater_dur_ms;

    rslt = bme68x_set_heatr_conf(BME68X_FORCED_MODE, &s_heatr_conf, &s_dev);
    if (rslt != BME68X_OK) {
        ESP_LOGE(TAG, "bme68x_set_heatr_conf failed: %d", rslt);
        return ESP_FAIL;
    }

    s_initialized = true;
    ESP_LOGI(TAG, "BME68x initialized (addr=0x%02X)", config->i2c_addr);
    return ESP_OK;
}

esp_err_t bme68x_driver_read(struct bme68x_data *out)
{
    if (!s_initialized || !out) {
        return ESP_ERR_INVALID_STATE;
    }

    int8_t rslt = bme68x_set_op_mode(BME68X_FORCED_MODE, &s_dev);
    if (rslt != BME68X_OK) {
        return ESP_FAIL;
    }

    uint32_t meas_dur_us = bme68x_get_meas_dur(BME68X_FORCED_MODE, &s_conf, &s_dev);
    delay_us(meas_dur_us, nullptr);

    uint8_t n_fields = 0;
    rslt = bme68x_get_data(BME68X_FORCED_MODE, out, &n_fields, &s_dev);
    if (rslt != BME68X_OK || n_fields == 0) {
        return ESP_FAIL;
    }

    return ESP_OK;
}

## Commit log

2026-02-05 Bootstrap esp-matter env sensor baseline
    - Base project structure from esp-matter sensors example, configs, and partitions
    - Add BME68x and BSEC2 components and supporting configs
    - Add ZAP model (wall_env.zap) and generated outputs
    - Bring up I2C bus wrapper and migrate SHTC3 to i2c_master
    - Add build/warning helper scripts
    [partitions.csv]
2026-02-05 Add BME680+BSEC2 sensor loop and Thread commissioning config
    - Add BME68x I2C driver wrapper + shared I2C helpers\n- Integrate BSEC2 LP processing loop with periodic logs and NVS state save/restore\n- Update Matter attributes for temp/RH/pressure/air quality a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
2026-02-06 Add SSD1306 OLED splash and status screen
    - Add SSD1306 I2C driver/task (addr 0x3C default)\n- Splash: centered 2-line text for 5000ms\n- Runtime screen: T/RH/P/IAQ/CO2 pulled from BSEC2 latest snapshot\n- Add Kconfig + sdkconfig.defaults kn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
2026-02-06 Switch OLED driver to SH1106 (was SSD1306)
    - Update init sequence for SH1106\n- Use per-page writes with configurable column offset (default +2)\n- Add CONFIG_WALL_ENV_OLED_COL_OFFSET
2026-02-06 Rename OLED driver to SH1106
    - Rename oled_ssd1306.* to oled_sh1106.*\n- Update app_main include/call
2026-02-06 Use ZAP single-endpoint data model (remove runtime endpoints)
    - Stop creating dynamic sensor endpoints in app_main\n- Use ZAP-generated endpoint 1 with measurement + air quality + CO2 clusters\n- Wire BSEC2 attribute updates to the single endpoint\n- Reduce max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
2026-02-06 Initialize network commissioning + Identify for ZAP model
    - Add init_network_driver() (Thread commissioning)\n- Call network driver init + identification helpers after esp_matter::start
2026-02-06 Thread-only: prune Wi-Fi/Ethernet clusters and bind mDNS to OpenThread
    - Remove Wi‑Fi/Ethernet Network Diagnostics clusters from root endpoint in wall_env.zap\n- Regenerate main/zap-generated from updated .zap\n- Disable mDNS predefined STA/AP/ETH netifs and register Op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
2026-02-06 Thread-only: regen sdkconfig and pin mDNS/netif settings
    - Regenerate sdkconfig via set-target esp32c6\n- Ensure minimal mDNS is disabled and mDNS predefined STA/AP/ETH netifs are off\n- Clarify Wi-Fi disablement approach for ESP32-C6 (disable features, no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
2026-02-06 checkpoint: latest working before time-sync and OLED dimming
    [partitions.csv]
2026-02-07 build(config): switch to espressif/button and refresh device defaults
2026-02-07 feat(sensor): tune BSEC cadence, offset, and Fahrenheit logging
2026-02-13 Adde: Temp Offset runtime switch, Comm/Decomm hardening
    • Temp Offset switch can alter temperature offset at runtime to accommodate for different airflow/cooling in v1 case design vs the v2 case design. type 'profile <v1/v2>' to set offset for case design.
    • General logging/hardening for decommission flow and commission flow.
2026-03-06 First Combined device type test
2026-03-06 feat(calibration): add serial custom temperature offset profile
2026-03-06 Added explicit Thread Router functionality assignment
2026-04-23 Configurable reset button and supermini profile
    Add Kconfig option for factory reset button (WALL_ENV_RESET_BUTTON_GPIO) and use it in app_main to allow disabling or remapping the reset button; treat negative values as disabled. Log commissioning/fabric state on boot to aid diagnostics. Introduce a Supermini board sdkconfig overlay (sdkconfig.boards/supermini.defaults) and update sdkconfig.defaults/sdkconfig to reflect Supermini I2C pin mapping and reset defaults. Add helper scripts (tools/build-supermini.sh and tools/set-target-esp32c6-supermini.sh) to build/set-target with the Supermini profile. Update AGENTS.md with Matter conformance/defaults, common mistakes, and Codex ESP-IDF workflow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
    [app_main.cpp]
2026-04-23 Migrate to managed esp-matter and fix managed build parity
    [app_main.cpp]
2026-04-23 Use board-specific build directories in wrapper scripts
2026-04-23 Add board-specific flash wrapper scripts
    Introduce two convenience wrappers so flashing uses the correct board-specific build directory by default, matching the recent split-build workflow.
    - tools/flash.sh targets builds/xiao_esp32c6
    - tools/flash-supermini.sh targets builds/supermini_esp32c6
    - Both delegate to tools/idf.sh flash and preserve passthrough args
    This removes the need to manually set IDF_BUILD_DIR for normal flash flows while keeping the existing idf.sh behavior unchanged for advanced use.
2026-04-23 Ignore board-specific build output directory
    Add builds/* to .gitignore so board-separated build artifacts are not tracked.
2026-04-23 Allow flash wrappers to run erase+flash action chains
    Update tools/flash.sh and tools/flash-supermini.sh to pass through arbitrary idf actions. If no arguments are provided, they still default to flash. This enables one-command flows like: flash-supermi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
2026-04-26 Add board-safe force flash wrappers
    Default the ESP-IDF wrapper to the XIAO build directory so plain wrapper usage no longer falls back to the stale root build/ tree. Add flash-bin/force-flash support that calls esptool.py directly against the existing build flash_args file, bypassing idf.py, Ninja, and CMake when flashing a known-good board build. Add XIAO and Supermini convenience wrappers and restore the active sdkconfig to the XIAO pin profile.
2026-05-06 Added reference material and edited scripts
2026-05-06 Add 4MB Matter OTA requestor support
    Implement dual-slot OTA partitioning for the 4MB XIAO ESP32-C6 and ESP32-C6 Supermini profiles, enable Matter OTA Requestor support with ESP-IDF rollback validation, and split board Product IDs under the local test VID.
    Regenerate the Matter data model with the OTA Requestor endpoint 0 surface, fix ZAP compliance warnings, and update ZAP regen tooling to find the esp-matter zap-cli/templates from the local toolchain.
    Add OTA build packaging tooling with a 10 percent slot-free gate plus local documentation for OTA image creation, provider setup, versioning rules, and rollback behavior.
    [partitions.csv]
2026-05-07 Harden OTA bring-up and add release policy
    Make OTA requestor init stack-lock safe and allow bare-board bring-up by treating BSEC init failure as non-fatal.
    Update OTA packaging/version checks for 1.3.1 metadata flow and add a Matter OTA release policy documenting versioning, compatibility gates, and publishing procedure.
    [app_main.cpp]
2026-05-07 Simplify OTA version flow and harden OTA packaging checks
    - Keep PROJECT_VER/PROJECT_VER_NUMBER in CMakeLists as canonical numeric version source for OTA packaging.
    - Add tools/update-version.sh to update true source files only (CMakeLists + chip software version string macro).
    - Fix chip project version string handling to avoid build breaks in esp-matter compilation units.
    - Harden tools/build-ota.sh with explicit version consistency checks, default min applicable version (10300), and fix silent early-exit behavior under set -e.
    - Update OTA requestor/release policy docs with source-of-truth and gating rules for safe OTA rollout on 4MB dual-slot layouts.
    [app_main.cpp]
2026-05-14 Added Enclosure STL files
    [1.3- Screen Lid - Hosyond - Lid - OLED.stl, 1.3- Screen Lid - Hosyond - OLED Retaining Bracket.stl, Main Housing - Main Housing.stl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]
2026-05-14 Remove incomplete Hosyond OLED STL files
    [1.3- Screen Lid - Hosyond - Lid - OLED.stl, 1.3- Screen Lid - Hosyond - OLED Retaining Bracket.stl]
